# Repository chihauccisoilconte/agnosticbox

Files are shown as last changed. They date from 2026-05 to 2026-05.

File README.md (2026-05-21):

# Agnostic Box

This repository contains the files necessary to make an Agnostic Box.

The Agnostic Box is a versatile DMI (Digital Musical Instrument) that can be programmed in many ways. It is powered by an Arduino Nano ESP32, so it can run different interactive music, sound, and sensor-based sketches; this repository provides example sketches using the Mozzi audio synthesis library. The box is equipped with three potentiometers, three buttons, three LEDs, an MPU6050/GY-521 motion sensor connected over I2C, and a PAM8302A amplifier, giving it a compact set of tactile, visual, motion, and audio features for building custom musical interactions.

## Author

Created by [chihauccisoilconte](https://chihauccisoilconte.eu/).

The Agnostic Box is an idea by Raul Masu and Nicolo Merendino (aka chi ha ucciso il conte?).

## Contents

- `agnostic box instruction manual.pdf` - build and assembly documentation.
- `agnostic box PCB/` - KiCad PCB files, Gerber files, drill files, PCB exports, and related PCB assets.
- `agonstic box 3D models/` - FreeCAD source files and STL/3MF files for 3D-printed parts.
- `agnostic box 2d vectors/` - 2D vector files and sticker artwork.
- `agnostic box arduino nano esp32 code/` - Arduino Nano ESP32 sketches.

## License

MIT License

Copyright (c) 2026 chihauccisoilconte

Permission is hereby granted, free of charge, to any person obtaining a copy
of this repository and associated documentation files (the "Work"), to deal
in the Work without restriction, including without limitation the rights
to use, copy, modify, merge, publish, distribute, sublicense, and/or sell
copies of the Work, and to permit persons to whom the Work is furnished to do
so, subject to the following conditions:

The above copyright notice and this permission notice shall be included in all
copies or substantial portions of the Work.

THE WORK IS PROVIDED "AS IS", WITHOUT WARRANTY OF ANY KIND, EXPRESS OR
IMPLIED, INCLUDING BUT NOT LIMITED TO THE WARRANTIES OF MERCHANTABILITY,
FITNESS FOR A PARTICULAR PURPOSE AND NONINFRINGEMENT. IN NO EVENT SHALL THE
AUTHORS OR COPYRIGHT HOLDERS BE LIABLE FOR ANY CLAIM, DAMAGES OR OTHER
LIABILITY, WHETHER IN AN ACTION OF CONTRACT, TORT OR OTHERWISE, ARISING FROM,
OUT OF OR IN CONNECTION WITH THE WORK OR THE USE OR OTHER DEALINGS IN THE
WORK.

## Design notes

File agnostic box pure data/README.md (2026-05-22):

# Agnostic Box Pure Data Patch

This folder contains a Pure Data patch for using the Agnostic Box as a serial controller for FM synthesis.

The patch `arduino_controlling_FM_synth.pd` receives the serial array sent by the Arduino Nano ESP32, separates the values in Pure Data, and uses them to control an FM sine synthesizer.

## Install Pure Data

Download and install Pure Data Vanilla:

- Pure Data project site: <https://puredata.info/>
- Pure Data source and install notes: <https://github.com/pure-data/pure-data>
- Miller Puckette's Pd download page: <http://msp.ucsd.edu/software.html>

After installing Pd, open it once and check that audio works:

1. Open `Media > Audio Settings...`.
2. Select your audio input/output device.
3. Turn on `DSP` in the main Pd window.
4. Open `Media > Test Audio and MIDI...` if you want to confirm sound output.

## Install the `comport` External

The patch uses the `[comport]` object to read serial data from the Agnostic Box. `[comport]` is not part of Pd Vanilla, so install it with Deken, Pd's external/package manager.

Useful links:

- Deken documentation: <https://deken.puredata.info/docs>
- Deken external search: <https://deken.puredata.info/search.html>
- Pd external installation is also described in the Pure Data README: <https://github.com/pure-data/pure-data>

Install from inside Pure Data:

1. Open Pd.
2. Go to `Help > Find Externals...`.
3. Search for `comport`.
4. Install the package that matches your operating system.
5. Restart Pure Data.
6. Create a new object called `[comport]`. If it creates without an error, the install worked.

## Upload the Arduino Serial Sketch

Upload the mapped serial sketch to the Arduino Nano ESP32:

```text
../agnostic box arduino nano esp32 code/sensor_mapped_serial_test/sensor_mapped_serial_test.ino
```

That sketch sends seven values over serial:

```text
pot0 pot1 pot2 button0 button1 button2 gyro
```

The mapped values are:

- `pot0`, `pot1`, `pot2`: `1-127`
- `button0`, `button1`, `button2`: `0` or `1`
- `gyro`: `0-127`, based on `0-90` degrees, clamped for out-of-range motion

The Arduino sketch uses:

```cpp
Serial.begin(115200);
```

So the Pd patch should use the same baud rate:

```text
[comport 0 115200]
```

If the existing patch has another baud rate, edit the `[comport]` object so it matches the Arduino sketch.

## Connect the Agnostic Box to Pure Data

1. Connect the Agnostic Box by USB.
2. Close the Arduino Serial Monitor. Only one program can usually use the serial port at a time.
3. Open `arduino_controlling_FM_synth.pd` in Pure Data.
4. Turn on `DSP`.
5. Click the `devices` message in the patch.
6. Check the Pd console for the serial device list.
7. Change the `open 0` message if needed. For example, use `open 1`, `open 2`, etc. depending on the listed device number.
8. Click the correct `open` message.

If serial data is arriving, the number boxes after `[unpack f f f f f f f]` should update when you turn knobs, press buttons, or tilt the box.

## How the Serial Parsing Works

The Arduino sends a line of space-separated numbers, ending with a newline:

```text
64 23 127 0 1 0 45
```

In the Pd patch:

- `[comport]` receives raw serial bytes.
- `[sel 13 10]` detects carriage return and newline characters.
- The list-building objects collect each line.
- `[fudiparse]` converts the incoming text into Pd numbers.
- `[unpack f f f f f f f]` separates the seven values.

The value order is:

```text
1. pot0
2. pot1
3. pot2
4. button0
5. button1
6. button2
7. gyro
```

## Using the Values for FM Synthesis

FM synthesis uses one oscillator to modulate the frequency of another oscillator.

In this patch:

- `[osc~]` objects generate sine waves.
- `[mtof]` converts controller values into musical frequencies.
- `[*~]` scales modulation depth.
- `[+~]` adds modulation to the carrier frequency.
- `[dac~]` sends the final audio to the speakers.

A useful control layout is:

- `pot0`: carrier pitch
- `pot1`: modulator pitch
- `pot2`: modulation depth or output level
- `gyro`: extra modulation depth, feedback, or vibrato-like movement
- `button0`, `button1`, `button2`: enable/disable modulation paths, hold notes, or switch presets

Start with low volume before turning on DSP. FM patches can get loud quickly when modulation depth or feedback is high.

## Troubleshooting

- If `[comport]` says it cannot create, install the `comport` external with `Help > Find Externals...` and restart Pd.
- If the device will not open, close Arduino IDE Serial Monitor and any other serial terminal.
- If values do not move, click `devices`, confirm the device number, then send the matching `open` message.
- If the values look wrong, make sure the Pd baud rate matches `Serial.begin(115200)` in the Arduino sketch.
- On Linux, your user may need permission to access serial devices such as `/dev/ttyACM0` or `/dev/ttyUSB0`.

## Credits

Created for the Agnostic Box project by chihauccisoilconte.

This Pure Data patch uses Pure Data Vanilla and the `comport` external for serial communication.

## License

MIT License

Copyright (c) 2026 chihauccisoilconte

Permission is hereby granted, free of charge, to any person obtaining a copy
of this repository and associated documentation files (the "Work"), to deal
in the Work without restriction, including without limitation the rights
to use, copy, modify, merge, publish, distribute, sublicense, and/or sell
copies of the Work, and to permit persons to whom the Work is furnished to do
so, subject to the following conditions:

The above copyright notice and this permission notice shall be included in all
copies or substantial portions of the Work.

THE WORK IS PROVIDED "AS IS", WITHOUT WARRANTY OF ANY KIND, EXPRESS OR
IMPLIED, INCLUDING BUT NOT LIMITED TO THE WARRANTIES OF MERCHANTABILITY,
FITNESS FOR A PARTICULAR PURPOSE AND NONINFRINGEMENT. IN NO EVENT SHALL THE
AUTHORS OR COPYRIGHT HOLDERS BE LIABLE FOR ANY CLAIM, DAMAGES OR OTHER
LIABILITY, WHETHER IN AN ACTION OF CONTRACT, TORT OR OTHERWISE, ARISING FROM,
OUT OF OR IN CONNECTION WITH THE WORK OR THE USE OR OTHER DEALINGS IN THE
WORK.

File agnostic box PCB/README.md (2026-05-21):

# Agnostic Box PCB

This folder contains the PCB files for the Agnostic Box.

The PCB was made with [KiCad](https://www.kicad.org/), an open source electronics design suite. The folder includes KiCad project files, schematic and PCB layout files, Gerber files, drill files, board backups, graphics, footprints, and PCB export files.

Use the KiCad project files to inspect or modify the schematic and PCB layout. Use the Gerber and drill files when ordering or manufacturing the PCB.

For travel and safety, the standard Agnostic Box build does not include a battery. The PCB still includes the possibility of adding one through the battery footprint/connection, so builders can adapt the power setup if their use case requires it.

## License

MIT License

Copyright (c) 2026 chihauccisoilconte

Permission is hereby granted, free of charge, to any person obtaining a copy
of this repository and associated documentation files (the "Work"), to deal
in the Work without restriction, including without limitation the rights
to use, copy, modify, merge, publish, distribute, sublicense, and/or sell
copies of the Work, and to permit persons to whom the Work is furnished to do
so, subject to the following conditions:

The above copyright notice and this permission notice shall be included in all
copies or substantial portions of the Work.

THE WORK IS PROVIDED "AS IS", WITHOUT WARRANTY OF ANY KIND, EXPRESS OR
IMPLIED, INCLUDING BUT NOT LIMITED TO THE WARRANTIES OF MERCHANTABILITY,
FITNESS FOR A PARTICULAR PURPOSE AND NONINFRINGEMENT. IN NO EVENT SHALL THE
AUTHORS OR COPYRIGHT HOLDERS BE LIABLE FOR ANY CLAIM, DAMAGES OR OTHER
LIABILITY, WHETHER IN AN ACTION OF CONTRACT, TORT OR OTHERWISE, ARISING FROM,
OUT OF OR IN CONNECTION WITH THE WORK OR THE USE OR OTHER DEALINGS IN THE
WORK.

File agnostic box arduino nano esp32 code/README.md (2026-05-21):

# Agnostic Box Arduino Nano ESP32 Code

This folder contains Arduino sketches for the Agnostic Box.

The code is made for the Arduino Nano ESP32 and is intended to be opened and uploaded with the [Arduino IDE](https://www.arduino.cc/en/software). Some sketches use the [Mozzi](https://github.com/sensorium/Mozzi) audio synthesis library.

## Arduino IDE Setup

1. Install the Arduino IDE from <https://www.arduino.cc/en/software>.
2. Open the Arduino IDE.
3. Open `Tools > Board > Boards Manager...`.
4. Search for `Nano ESP32`.
5. Install the Arduino Nano ESP32 board package.
6. Select the board from `Tools > Board`.
7. Select the correct USB port from `Tools > Port`.

For generic ESP32 board support, add this URL in `File > Preferences > Additional boards manager URLs`, then install the `esp32` platform from Boards Manager:

```text
https://espressif.github.io/arduino-esp32/package_esp32_index.json
```

## Mozzi Library Setup

1. Open `Sketch > Include Library > Manage Libraries...`.
2. Search for `Mozzi`.
3. Install the Mozzi library.
4. Open one of the sketches in this folder.
5. Compile and upload it to the Arduino Nano ESP32.

## License

MIT License

Copyright (c) 2026 chihauccisoilconte

Permission is hereby granted, free of charge, to any person obtaining a copy
of this repository and associated documentation files (the "Work"), to deal
in the Work without restriction, including without limitation the rights
to use, copy, modify, merge, publish, distribute, sublicense, and/or sell
copies of the Work, and to permit persons to whom the Work is furnished to do
so, subject to the following conditions:

The above copyright notice and this permission notice shall be included in all
copies or substantial portions of the Work.

THE WORK IS PROVIDED "AS IS", WITHOUT WARRANTY OF ANY KIND, EXPRESS OR
IMPLIED, INCLUDING BUT NOT LIMITED TO THE WARRANTIES OF MERCHANTABILITY,
FITNESS FOR A PARTICULAR PURPOSE AND NONINFRINGEMENT. IN NO EVENT SHALL THE
AUTHORS OR COPYRIGHT HOLDERS BE LIABLE FOR ANY CLAIM, DAMAGES OR OTHER
LIABILITY, WHETHER IN AN ACTION OF CONTRACT, TORT OR OTHERWISE, ARISING FROM,
OUT OF OR IN CONNECTION WITH THE WORK OR THE USE OR OTHER DEALINGS IN THE
WORK.

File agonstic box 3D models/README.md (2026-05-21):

# Agnostic Box 3D Models

This folder contains the 3D model files for the Agnostic Box.

The source models were made with [FreeCAD](https://www.freecad.org/). The folder includes FreeCAD source files, STL files, and a 3MF file for 3D printing the mechanical parts.

It is recommended to 3D print the parts with PLA. Open the FreeCAD files if you need to inspect or modify the models, and use the STL or 3MF files for slicing and printing.

## License

MIT License

Copyright (c) 2026 chihauccisoilconte

Permission is hereby granted, free of charge, to any person obtaining a copy
of this repository and associated documentation files (the "Work"), to deal
in the Work without restriction, including without limitation the rights
to use, copy, modify, merge, publish, distribute, sublicense, and/or sell
copies of the Work, and to permit persons to whom the Work is furnished to do
so, subject to the following conditions:

The above copyright notice and this permission notice shall be included in all
copies or substantial portions of the Work.

THE WORK IS PROVIDED "AS IS", WITHOUT WARRANTY OF ANY KIND, EXPRESS OR
IMPLIED, INCLUDING BUT NOT LIMITED TO THE WARRANTIES OF MERCHANTABILITY,
FITNESS FOR A PARTICULAR PURPOSE AND NONINFRINGEMENT. IN NO EVENT SHALL THE
AUTHORS OR COPYRIGHT HOLDERS BE LIABLE FOR ANY CLAIM, DAMAGES OR OTHER
LIABILITY, WHETHER IN AN ACTION OF CONTRACT, TORT OR OTHERWISE, ARISING FROM,
OUT OF OR IN CONNECTION WITH THE WORK OR THE USE OR OTHER DEALINGS IN THE
WORK.

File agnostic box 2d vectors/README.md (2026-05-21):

# Agnostic Box 2D Vectors

This folder contains 2D vector files and graphic assets for the Agnostic Box.

The 2D files were made with [Inkscape](https://inkscape.org/) and [FreeCAD](https://www.freecad.org/). The graphics can be laser engraved, or they can be printed as stickers.

Use the vector files as source artwork for editing, engraving, cutting, or sticker production.

## License

MIT License

Copyright (c) 2026 chihauccisoilconte

Permission is hereby granted, free of charge, to any person obtaining a copy
of this repository and associated documentation files (the "Work"), to deal
in the Work without restriction, including without limitation the rights
to use, copy, modify, merge, publish, distribute, sublicense, and/or sell
copies of the Work, and to permit persons to whom the Work is furnished to do
so, subject to the following conditions:

The above copyright notice and this permission notice shall be included in all
copies or substantial portions of the Work.

THE WORK IS PROVIDED "AS IS", WITHOUT WARRANTY OF ANY KIND, EXPRESS OR
IMPLIED, INCLUDING BUT NOT LIMITED TO THE WARRANTIES OF MERCHANTABILITY,
FITNESS FOR A PARTICULAR PURPOSE AND NONINFRINGEMENT. IN NO EVENT SHALL THE
AUTHORS OR COPYRIGHT HOLDERS BE LIABLE FOR ANY CLAIM, DAMAGES OR OTHER
LIABILITY, WHETHER IN AN ACTION OF CONTRACT, TORT OR OTHERWISE, ARISING FROM,
OUT OF OR IN CONNECTION WITH THE WORK OR THE USE OR OTHER DEALINGS IN THE
WORK.

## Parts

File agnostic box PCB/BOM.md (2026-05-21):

# Agnostic Box PCB Bill of Materials

Source files checked:

- `agnostic box PCB.kicad_sch`
- `agnostic box PCB.kicad_pcb`

This BOM is based on the KiCad schematic symbols and PCB footprints. The schematic uses generic values for several parts, so values that are only visible in PCB reference labels are noted below.

## Components

| Qty | References | Component | Value / specification | Footprint / package | Notes |
| ---: | --- | --- | --- | --- | --- |
| 1 | A1 | Arduino Nano compatible module | Arduino Nano or Arduino Nano ESP32 | `Module:Arduino_Nano` | PCB silkscreen says `Arduino Nano (or Nano esp32)`. |
| 1 | U1 | GY-521 accelerometer/gyro module | GY-521 / MPU5060 label in schematic | `gy521:GY-521` | Manufacturer field: `GODREAM FORDREAM CO., LIMITED`; MP field: `GY-521`. |
| 1 | J1 | PAM8302A audio amplifier connection | PAM8302A | `Connector_PinSocket_2.54mm:PinSocket_1x05_P2.54mm_Vertical` | The PCB footprint is a 1x05 2.54 mm socket/header for the amplifier module. |
| 1 | BT1 | Battery connector | 2-pin battery connector | `Connector_PinSocket_2.54mm:PinSocket_1x02_P2.54mm_Vertical` | PCB silkscreen label: `battery`. |
| 3 | D1, D2, D3 | LED | 5 mm through-hole LED | `LED_THT:LED_D5.0mm` | PCB labels: `LED1(D4)`, `LED2(D5)`, `LED3(D6)`. LED color is not specified in the KiCad files. |
| 3 | R1, R2, R3 | Resistor | 220 ohm | `Resistor_THT:R_Axial_DIN0207_L6.3mm_D2.5mm_P7.62mm_Horizontal` | The schematic value is generic `R`; `220` comes from PCB labels `R1-220`, `R2-220`, `R3-220`. |
| 3 | R4, R5, R6 | Resistor | 10k ohm | `Resistor_THT:R_Axial_DIN0207_L6.3mm_D2.5mm_P7.62mm_Horizontal` | The schematic value is generic `R`; `10k` comes from PCB labels `R4-10k`, `R5-10k`, `R6-10k`. |
| 3 | RV1, RV2, RV3 | Potentiometer | Resistance value not specified | `Potentiometer_THT:Potentiometer_Alps_RK163_Single_Horizontal` | PCB labels: `RV1(A1)`, `RV2(A2)`, `RV3(A3)`. |
| 3 | SW1, SW2, SW3 | Push button | 6 mm through-hole push button | `Button_Switch_THT:SW_PUSH_6mm` | PCB labels: `SW1(D10)`, `SW2(D11)`, `SW3(D12)`. |

## PCB-Only Mechanical Features

| Qty | Item | Footprint | BOM status |
| ---: | --- | --- | --- |
| 3 | M3 countersunk mounting holes | `MountingHole:MountingHole_3.2mm_M3_DIN965` | Excluded from KiCad BOM; no screws or hardware values are specified in the board file. |

## Notes

- No manufacturer part numbers are specified for the resistors, LEDs, switches, potentiometers, battery connector, Arduino module, or PAM8302A connector in the KiCad schematic.
- The resistor values `220 ohm` and `10k ohm` were taken from PCB reference labels, not from schematic value fields.
- Potentiometer resistance values are not specified in either the schematic values or PCB labels.

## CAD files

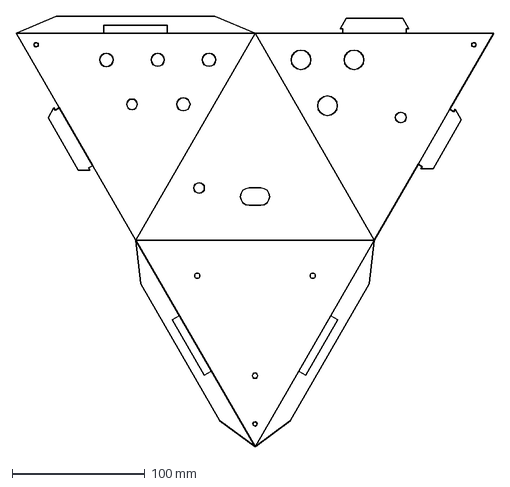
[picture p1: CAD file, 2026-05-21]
agnostic box 2d vectors/agnostic_box_pattern_workshop_final.dxf
360.0 x 324.8 mm

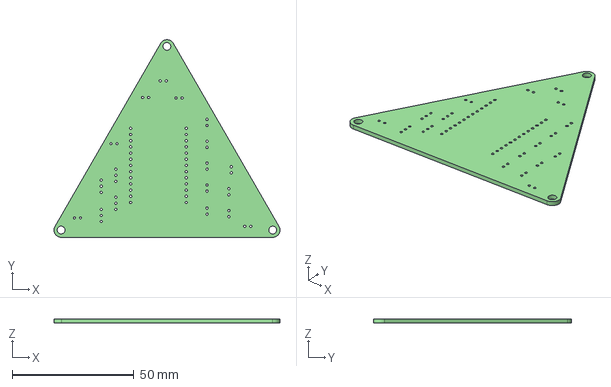
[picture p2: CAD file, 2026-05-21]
agnostic box PCB/agnostic box PCB.step
92.9 x 81.3 x 1.60 mm

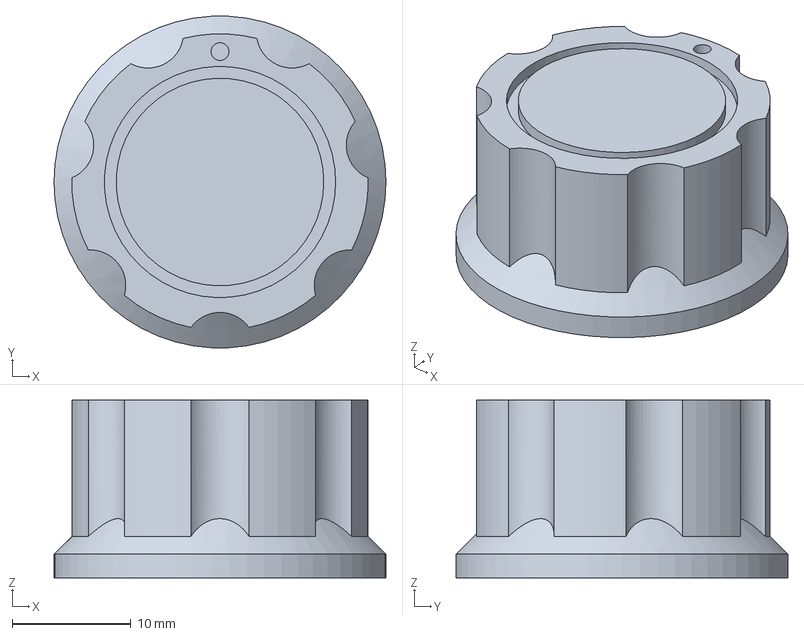
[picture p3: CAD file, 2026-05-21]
agonstic box 3D models/agnostic_box_nano_3d_models/knob.FCStd
28.0 x 28.0 x 15.0 mm

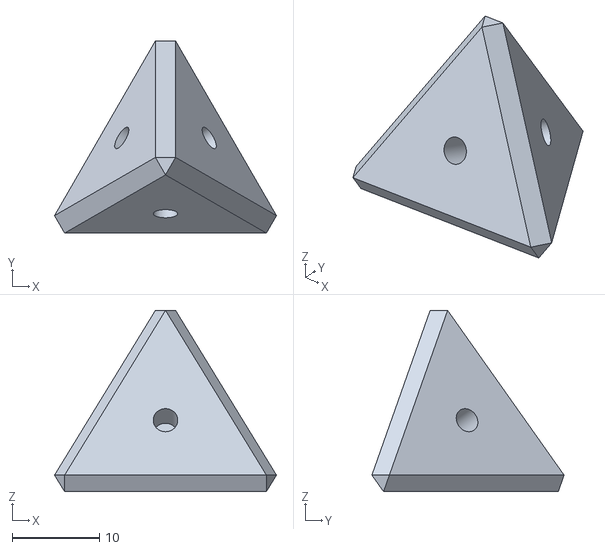
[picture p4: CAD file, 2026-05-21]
agonstic box 3D models/STL/4.2 - junction piece.stl
25.4 x 22.0 x 20.7

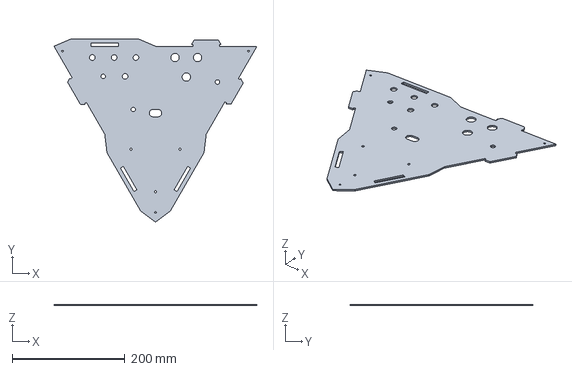
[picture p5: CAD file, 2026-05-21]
agnostic box 2d vectors/agnostic box pattern.FCStd
360.0 x 324.8 x 2.50 mm

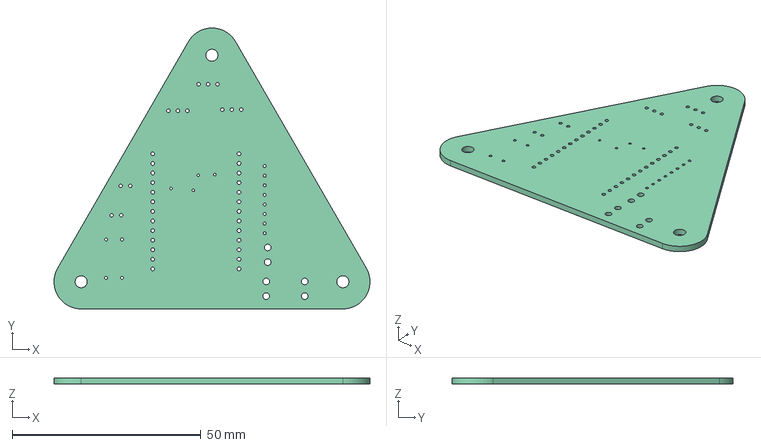
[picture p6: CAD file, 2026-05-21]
agnostic box PCB/pcb_3dmodel.FCStd
83.7 x 74.4 x 1.60 mm

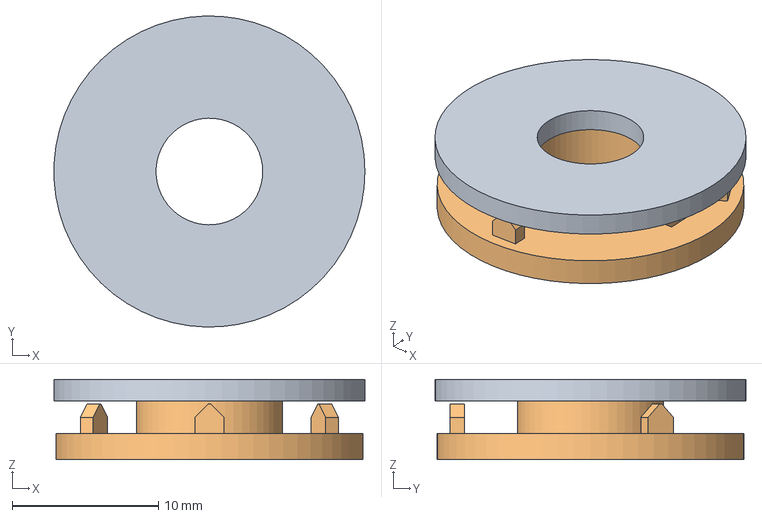
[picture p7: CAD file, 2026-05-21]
agonstic box 3D models/agnostic_box_nano_3d_models/knob_element.FCStd
21.3 x 21.3 x 5.50 mm
knob_piece_1
knob_piece_2

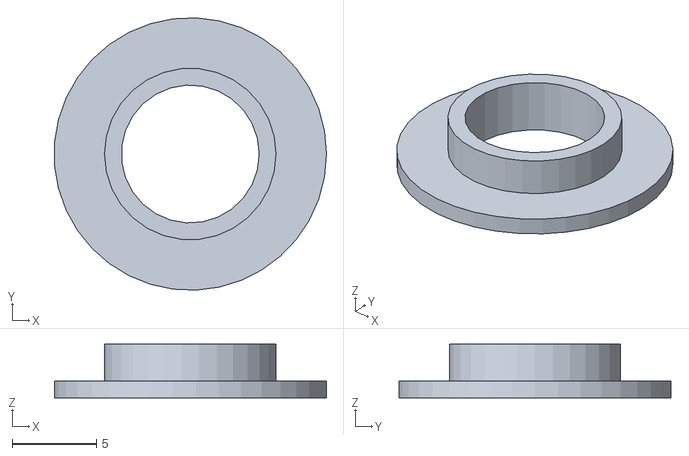
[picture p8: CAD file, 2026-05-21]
agonstic box 3D models/STL/3 - jack element 1 (thick).stl
16.2 x 16.2 x 3.20

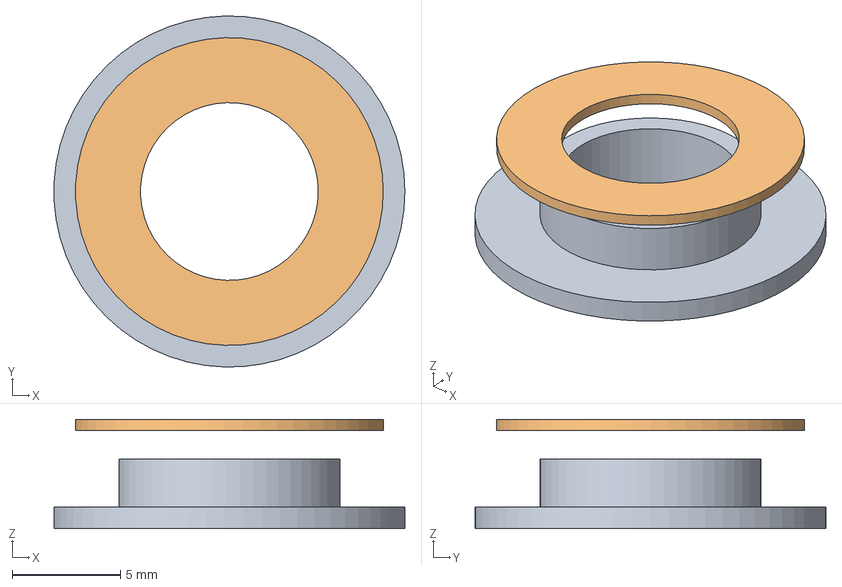
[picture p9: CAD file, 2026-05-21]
agonstic box 3D models/agnostic_box_nano_3d_models/jack__element-pop-os.FCStd
16.2 x 16.2 x 5.03 mm

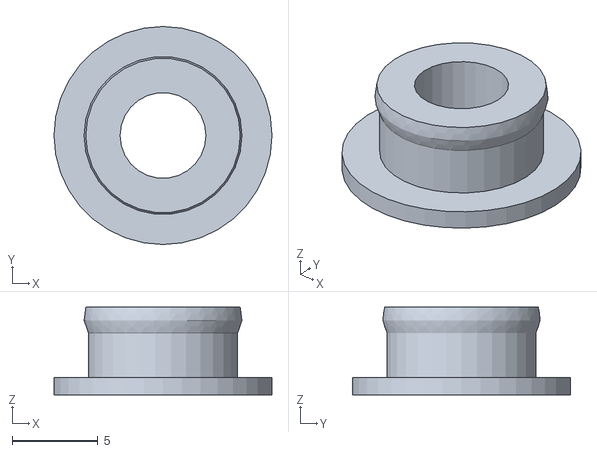
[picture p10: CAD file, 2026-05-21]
agonstic box 3D models/STL/7 - led holder.stl
12.7 x 12.7 x 5.10

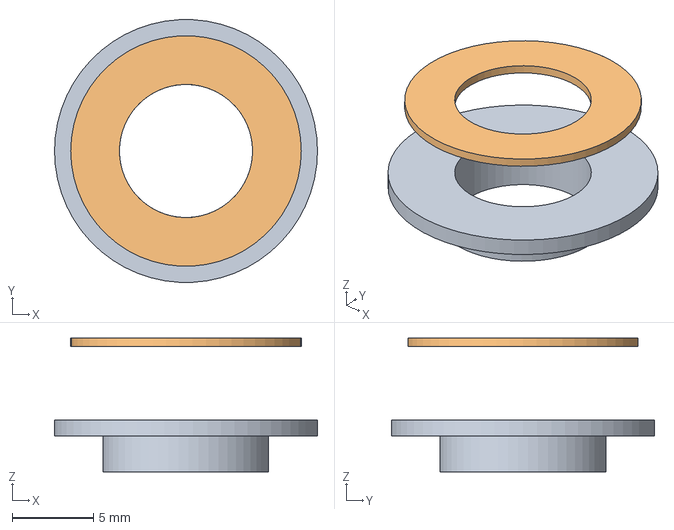
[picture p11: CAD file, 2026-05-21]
agonstic box 3D models/agnostic_box_nano_3d_models/jack__element.FCStd
16.2 x 16.2 x 8.23 mm

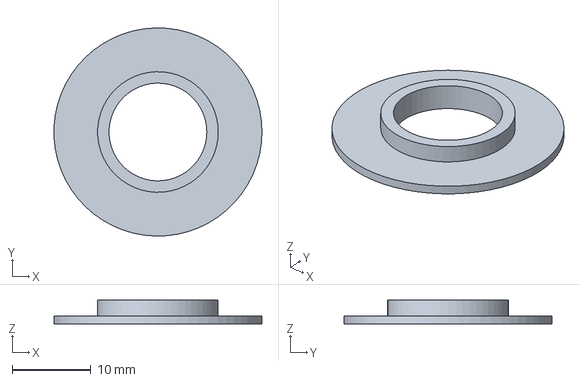
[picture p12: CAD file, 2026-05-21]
agonstic box 3D models/agnostic_box_nano_3d_models/button_element.FCStd
26.4 x 26.4 x 3.00 mm

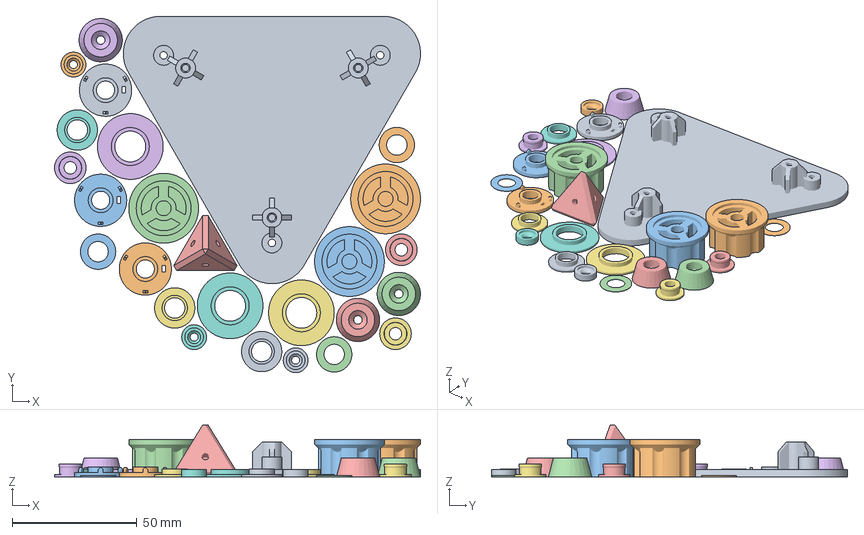
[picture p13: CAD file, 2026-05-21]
agonstic box 3D models/STL/agnostic_box_all.3mf
146.8 x 143.0 x 20.7 mm
1 - base.stl
5 - knob.stl x 3
4.2 - junction piece.stl
2 - button_element.stl x 3
6 - knob element.stl x 3
leg - element.stl x 3
3 - jack element 1 (thick).stl x 3
3.2 - jack element 2 (bearing).stl x 3
7 - led holder.stl x 3
4 junctioncap.stl x 3

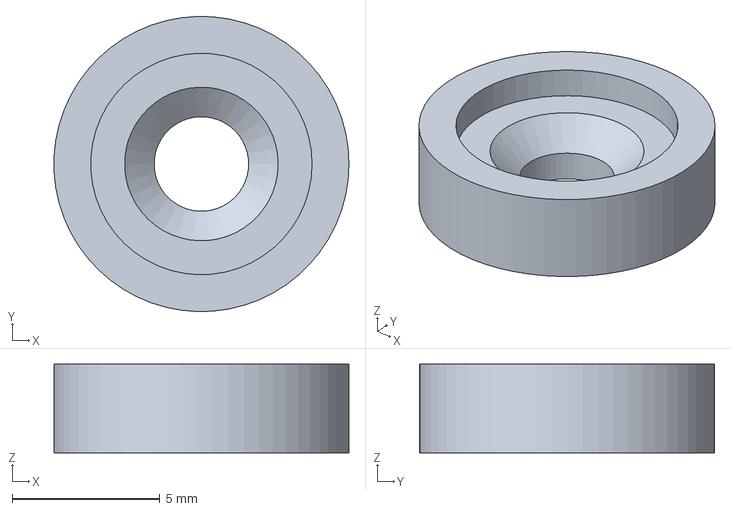
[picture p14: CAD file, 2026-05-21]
agonstic box 3D models/agnostic_box_nano_3d_models/junctioncap.FCStd
9.99 x 10.00 x 3.00 mm

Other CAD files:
agonstic box 3D models/STL/5 - knob.stl
agonstic box 3D models/STL/3.2 - jack element 2 (bearing).stl
agonstic box 3D models/agnostic_box_nano_3d_models/led_holder.FCStd
agonstic box 3D models/STL/6 - knob element.stl
agonstic box 3D models/STL/1 - base.stl
agonstic box 3D models/STL/2 - button_element.stl
agonstic box 3D models/STL/4 junctioncap.stl
agonstic box 3D models/STL/leg - element.stl
agonstic box 3D models/agnostic_box_nano_3d_models/base.FCStd
agonstic box 3D models/agnostic_box_nano_3d_models/junction element-pop-os.FCStd
agonstic box 3D models/agnostic_box_nano_3d_models/junction element.FCStd
agonstic box 3D models/agnostic_box_nano_3d_models/knob_element-pop-os.FCStd
agonstic box 3D models/agnostic_box_nano_3d_models/leg_element.FCStd

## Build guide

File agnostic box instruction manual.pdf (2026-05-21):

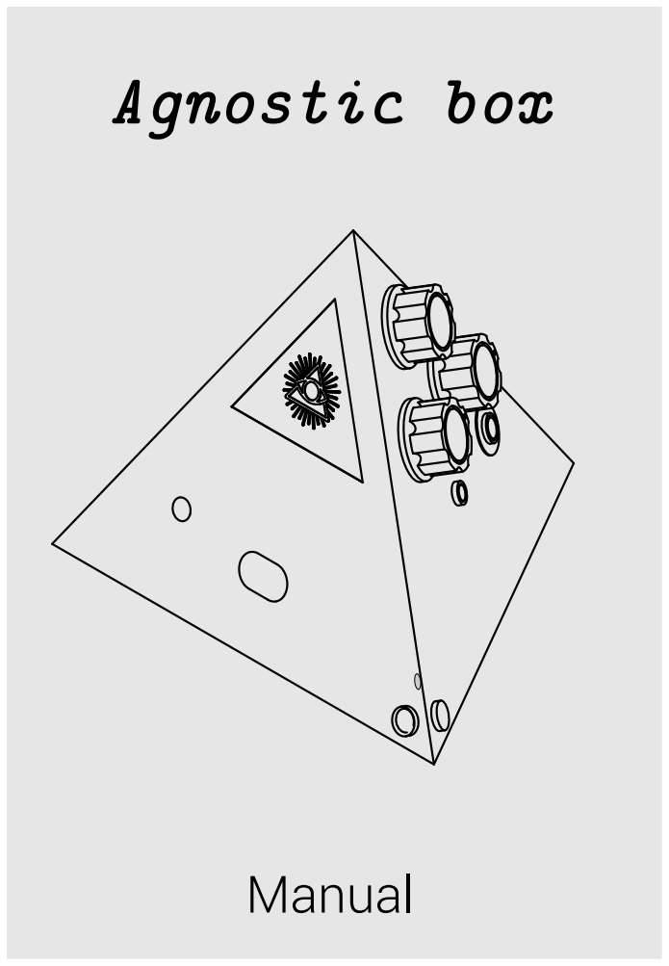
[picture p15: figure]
Agnostic box; Manual

MPU5060

PAM8302A

!

!

!

!

Resistors Colors
220 Ω
RD–RD–BK–BK–BN

### 10 kΩ

BN–BK–BK–RD–BN

The Agnostic Box is a completely open source, hackable sonic device designed for research and teaching. All source files and instructions are available in a public GitHub repository.

# Asnapshot!

Assemble the circuit using a soldering iron. Pay attention to the components that require a connector. The connector is there to allow easier assembly of a number of components.
The Arduino, amplifier, and acc/gyro should be placed on the PCB directly, though a connector is strongly recommended so you can eventually remove them and use them in other projects!
Note that the electronic components may differ from those shown in the images depending on the manufacturer, but the overall connections should be the same..

# Circuit

The folding lines of the
cardboard casing are
on the inside of the
box. It can be a good
idea to fold the pattern
first to get an idea of
how it works.

Note: For ease of
reading, messy wiring
is not visualized in
these illustrations.

# Cardboard pattern

# PCB placing

PCB support, casing
junction (be gentle on
that!), and LED
placement
Use hot glue to secure
the LED to the plastic
element.

Potentiometers, LED
(same as the others), and
audio jack
Make sure the orientation of the knobs is correct
(Wires perpendicular to the lower side of the face).

Switches and last LED
Disconnect the switches
using the connector, then
re-attach them.

Fold the cardboard
pattern
Keep the side with the
switch buttons as the
last part to fold. Then
secure the edges using
screws and bearings.

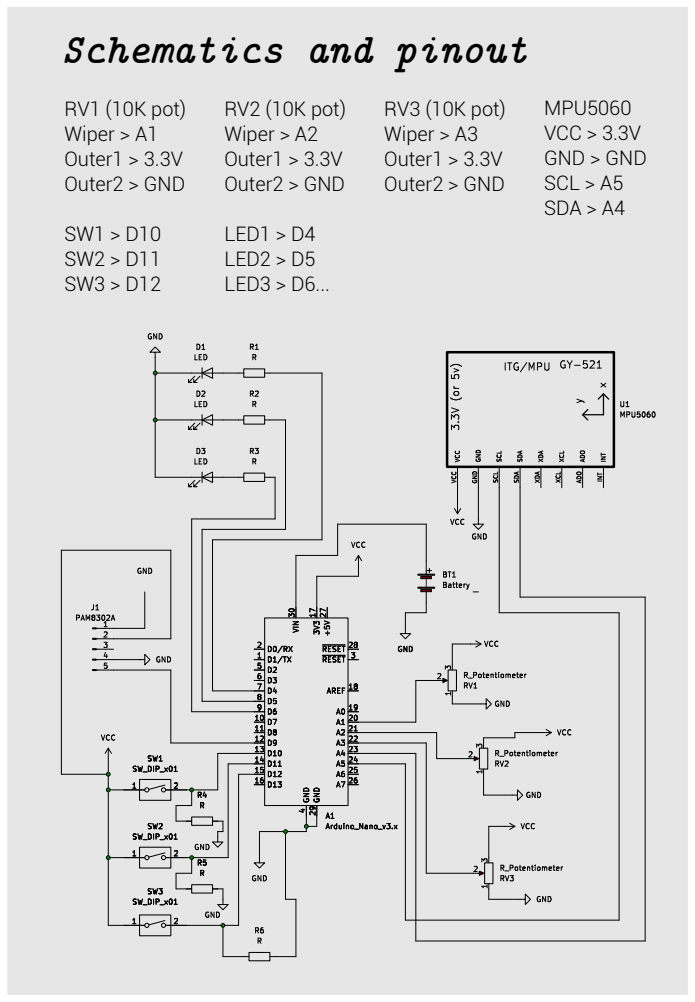
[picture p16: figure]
Schematics and pinout; MPU5060 VCC > 3.3V GND > GND SCL > A5 SDA > A4; RV3 (10K pot) Wiper > A3 Outer1 > 3.3V Outer2 > GND; LED1 > D4 LED2 > D5 LED3 > D6...; RV2 (10K pot) Wiper > A2 Outer1 > 3.3V Outer2 > GND; RV1 (10K pot) Wiper > A1 Outer1 > 3.3V Outer2 > GND

# Program the Agnostic Box!

What You'll Need
Hardware: Agnostic Box (Arduino Nano ESP32 inside) + USB-C cable
Software: Arduino IDE 2.x (arduino.cc/en/software)

Step-by-Step
Launch the IDE & Open Board Manager
Open the Arduino IDE. In the left sidebar, click the Boards Manager icon (cube shape).

Install the Board Package
In the search bar, type Nano ESP32. Click Install on the official Arduino ESP32 Boards package.

Connect Your Board
Plug the board into your computer using a USB-C cable.

Select Your Board
Click the board selector dropdown (often "Select Other Board & Port"). Find and select Arduino Nano ESP32. If two versions appear, choose the one labeled USB.

Write & Upload Your Code
Blink test: Go to File -> Examples -> 01.Basics -> Blink. Compile: Click the checkmark (top-left).

Upload: Click the right arrow next to it.

See the result
The built-in RGB LED on the board should start blinking.

Note - if your Agnostic Box is equipped with a classic Arduino Nano (or clone) you don't need any of this (but beware: no bluetooth and no wifi available)

# Meet the Agnostic Box!

The Agnostic Box is a simple and hackable sonic device designed for research and teaching purposes.
It contains 3 knobs, 3 buttons, a mono audio out jack, and an MPU6050 that detects acceleration and orientation.
The device is driven by an ESP32 Arduino Nano board, but it can also be used with a traditional Arduino Nano.
It is extremely versatile and can be programmed in many different ways according to your needs.
This device is completely open source. You can find all the source files and instructions in a public repository on GitHub.

By default the agnostic box is programmed with a Dub Siren-ish digital sythn that you can just plug to a speaker, but you can du much more...

# Agnostic Box and the Mozzi Library

# Agnostic Box and the BLE MIDI Library

The Mozzi library transforms your Agnostic Box into a powerful, standalone digital synthesizer. It's a sound synthesis library for Arduino that allows you to generate complex audio like growls, sweeps, and chorusing atmospherics using synthesis units like oscillators, delays, filters, and envelopes. For your box, the three knobs could control synthesis parameters such as frequency, filter cutoff, or amplitude. The three buttons could trigger different sound banks or envelopes. The MPU5060 could introduce gesture-controlled pitch bends or vibrato, while the three LEDs can provide real-time visual feedback of the synthesis state. Mozzi is available for the ESP32, making it a perfect fit for the Nano ESP32. The easiest way to get started is to install it directly from the Arduino Library Manager

# Agnostic Box and OSC Protocol

# Agnostic Box and whatever

https://github.com/sensorium/Mozzihttps://sensorium.github.io/Mozzi/https://docs.arduino.cc/hardware/nano-esp32

By using the BLE-MIDI protocol, your Agnostic Box becomes a natively recognized MIDI peripheral. This means that once connected, your computer, smartphone, or tablet will see the box as any other commercial Bluetooth MIDI controller—no special drivers or bridge scripts are required. This is because the Arduino Nano ESP32's ESP32-S3 chip, part of the u-blox NORA-W106 module, supports both Wi-Fi and Bluetooth Low Energy (LE). The key detail is that the Nano ESP32 is an ESP32-S3, which, unlike older ESP32 chips, can support MIDI over both BLE and USB simultaneously. In this setup, the three LEDs on your box can even be controlled by incoming MIDI messages from the DAW, creating a fully bidirectional wireless instrument.

https://www.midi.org/specifications/midi-transports-specifications/midi-over-bluetooth-lehttps://docs.arduino.cc/hardware/nano-esp32https://github.com/lathoub/arduin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

Open Sound Control (OSC) offers a more flexible and higher-resolution alternative to MIDI, and with the Nano ESP32's built-in Wi-Fi, you can implement this natively. You can use the MicroOsc library, a simple and lightweight Open Sound Control (OSC) library that supports the ESP32 platform. Your Agnostic Box can act as an OSC client over Wi-Fi, streaming sensor data directly. For instance, the three knobs could send float values as OSC messages like /box/ knob1 0.67, and the MPU5060 could send /box/imu/roll 45.2 to a target IP address and port where software like Pure Data or Max/ MSP is listening. MicroOsc provides a unified API to work over UDP (Ethernet or WiFi), making it ideal for this application. This approach avoids the need for a computer as a bridge, maintaining a clean and direct wireless connection.

https://explore.market.dev/ecosystems/arduino/projects/microoschttps://github.com/CNMAT/OSChttps://docs.arduino.cc/hardware/nano-esp32

Beyond synthesis and MIDI/OSC control, the Agnostic Box can serve as a multi‑purpose musical tool. The combination of knobs, buttons, an IMU, and LEDs makes it ideal for gestural performance: tilt the box to control filter sweeps while pressing buttons to trigger samples. You could use the MPU5060’s gyroscope to map bowing or shaking gestures to pitch bends, vibrato depth, or delay feedback. The three LEDs can be programmed as a visual metronome (blinking at BPM‑synced rates) or as a feedback display for note velocities. Over Wi‑Fi (using the Nano ESP32’s built‑in radio), the box can stream real‑time sensor data to a networked sound server running SuperCollider or Pure Data. Alternatively, use the board’s USB port to emulate a class‑compliant MIDI device—plugging directly into a computer without any driver installation. With the onboard memory, you could even store short wavetables or drum samples, turning the box into a minimal groovebox when combined with Mozzi’s sample playback features. The same three buttons could be repurposed as a step sequencer interface: each button toggles a step on/off, while knobs adjust pitch or velocity per step, and the LEDs light up to show the current playhead position. In an educational context, the box becomes a tangible platform for teaching synthesis, mapping, and sensor‑to‑sound relationships—all without soldering or external hardware beyond the Arduino Nano ESP32 itself.

# Credits

The agnostic box concept comes from an original idea from Raul Masu and Nicolo Merendino (aka "Chi ha Ucciso Il Conte?")

Design of the box and of this manual is by Nicolo Merendino (aka "Chi ha Ucciso Il Conte?")

Project funded by the HKUST-GZ

More info - chihauccisoilconte.eu

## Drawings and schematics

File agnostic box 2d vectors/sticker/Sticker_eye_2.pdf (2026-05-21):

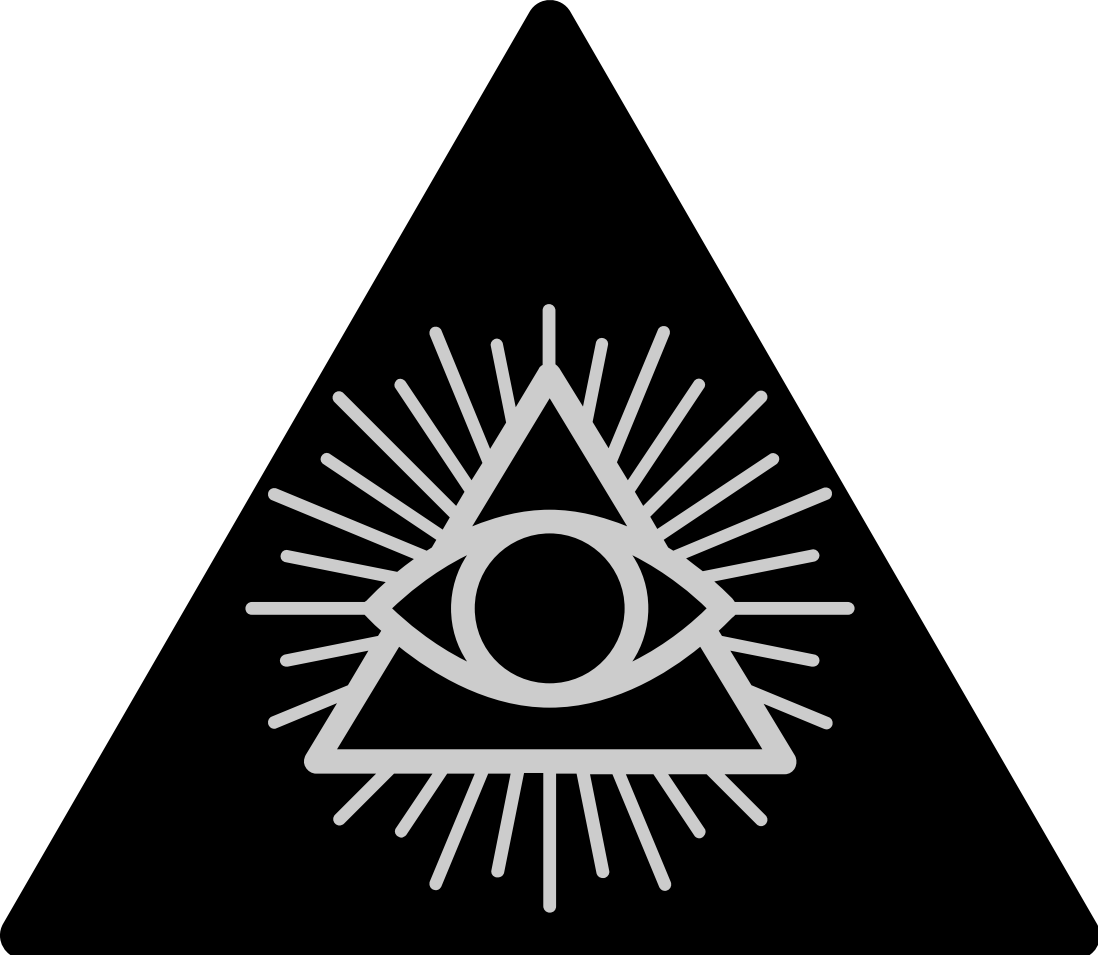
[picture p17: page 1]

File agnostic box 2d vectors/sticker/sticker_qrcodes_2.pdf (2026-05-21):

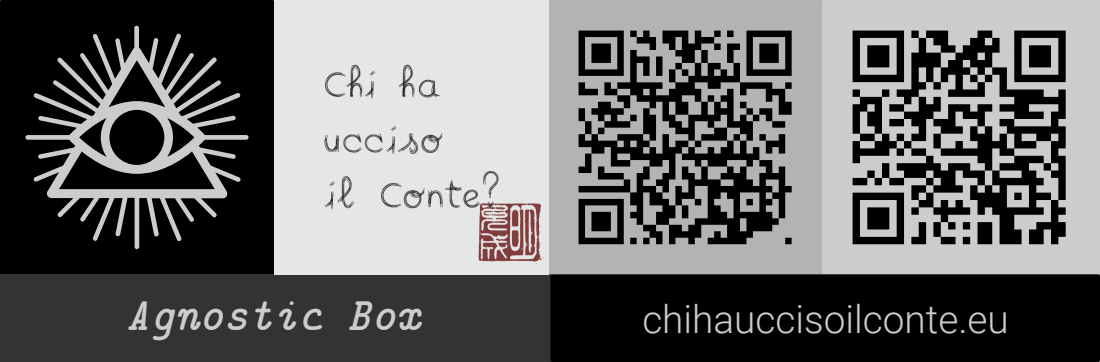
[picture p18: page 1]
Agnostic Box; chihauccisoilconte.eu

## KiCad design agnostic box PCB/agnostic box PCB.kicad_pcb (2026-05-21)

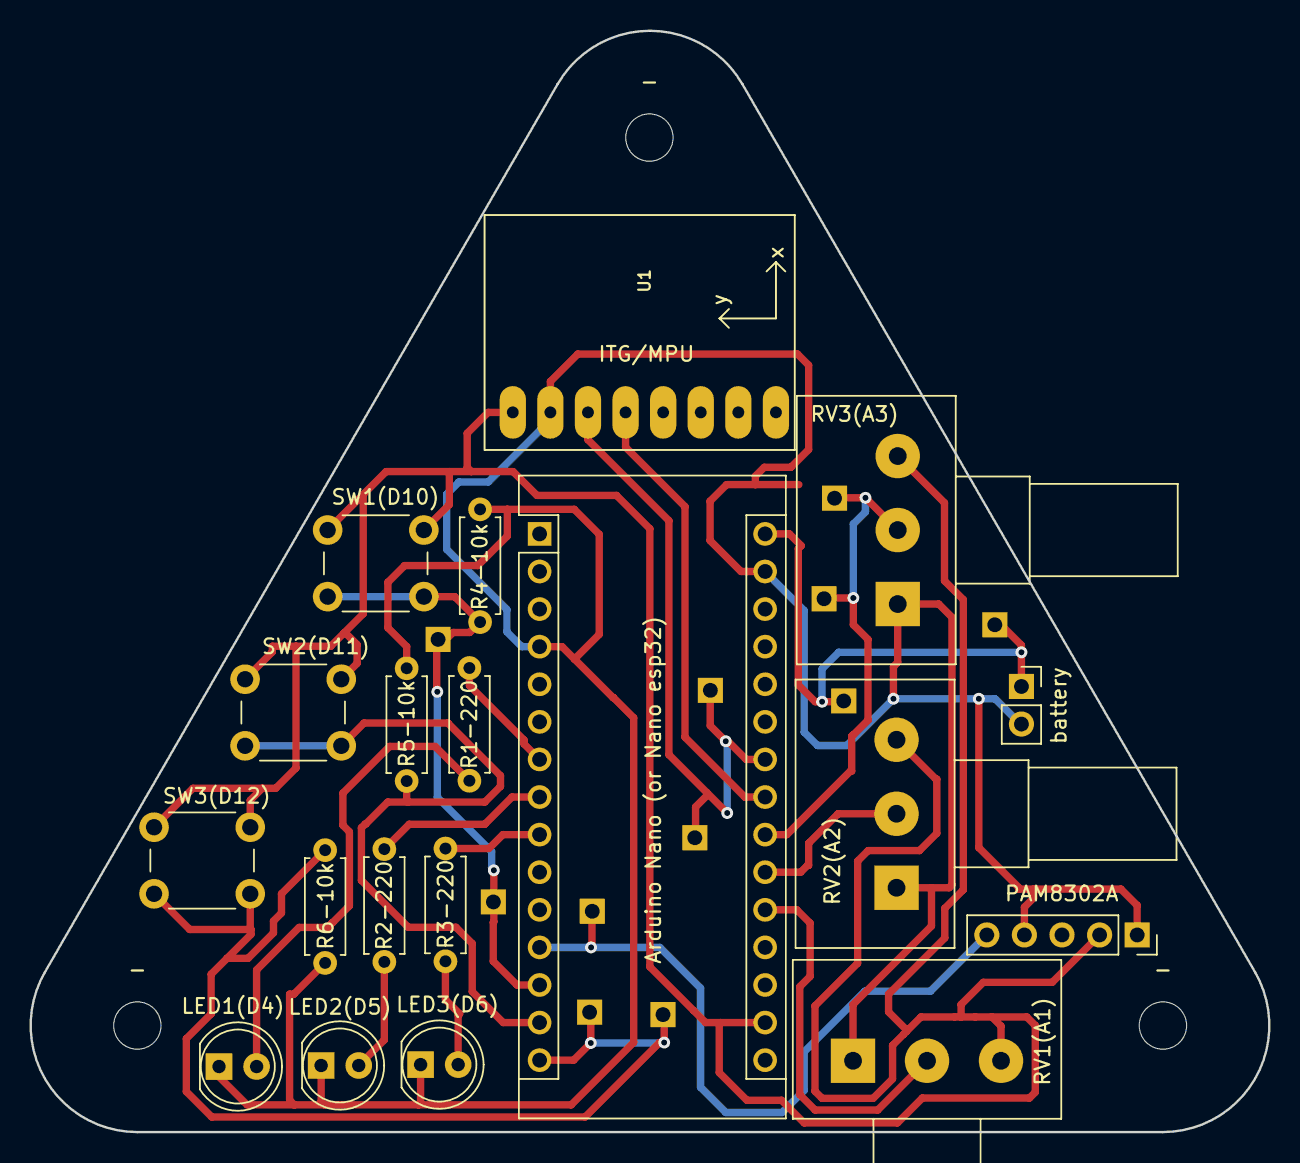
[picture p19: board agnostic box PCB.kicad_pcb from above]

Board: 2 copper layers, 83.7 x 74.4 mm, 22 parts (0 on the bottom side), 12 nets.

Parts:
-: MountingHole_3.2mm_M3_DIN965
-#2, -#3: MountingHole_3.2mm_M3_DIN965
Arduino Nano (or Nano esp32): Arduino_Nano_v3.x; Arduino_Nano
LED1(D4), LED2(D5), LED3(D6): LED; LED_D5.0mm
PAM8302A: PAM8302A; PinSocket_1x05_P2.54mm_Vertical
R1-220, R2-220, R3-220, R4-10k, R5-10k, R6-10k: R; R_Axial_DIN0207_L6.3mm_D2.5mm_P7.62mm_Horizontal
RV1(A1), RV2(A2), RV3(A3): R_Potentiometer; Potentiometer_Alps_RK163_Single_Horizontal
SW1(D10), SW2(D11), SW3(D12): SW_DIP_x01; SW_PUSH_6mm
U1: GY-521
battery: Battery; PinSocket_1x02_P2.54mm_Vertical

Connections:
GND: Arduino Nano (or Nano esp32).4 (GND), Arduino Nano (or Nano esp32).29 (GND), LED1(D4).1 (K), LED2(D5).1 (K), LED3(D6).1 (K), PAM8302A.1, PAM8302A.4, R4-10k.2, R5-10k.2, R6-10k.1, RV1(A1).1, RV2(A2).1, RV3(A3).1, U1.GND, battery.2 (-)
unnamed: Arduino Nano (or Nano esp32).20 (A1), RV1(A1).2
unnamed: Arduino Nano (or Nano esp32).21 (A2), RV2(A2).2
unnamed: Arduino Nano (or Nano esp32).22 (A3), RV3(A3).2
unnamed: Arduino Nano (or Nano esp32).23 (A4), U1.SDA
unnamed: Arduino Nano (or Nano esp32).24 (A5), U1.SCL
unnamed: Arduino Nano (or Nano esp32).12 (D9), PAM8302A.5
unnamed: Arduino Nano (or Nano esp32).13 (D10), SW1(D10).2
unnamed: Arduino Nano (or Nano esp32).14 (D11), SW2(D11).2
unnamed: Arduino Nano (or Nano esp32).15 (D12), SW3(D12).2
unnamed: Arduino Nano (or Nano esp32).30 (VIN), battery.1 (+)
VCC: Arduino Nano (or Nano esp32).17 (3V3), PAM8302A.2, RV1(A1).3, RV2(A2).3, RV3(A3).3, SW1(D10).1, SW2(D11).1, SW3(D12).1, U1.VCC

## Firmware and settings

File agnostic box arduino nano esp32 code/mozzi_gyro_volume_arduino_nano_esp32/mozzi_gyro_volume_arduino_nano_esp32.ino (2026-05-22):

#define MOZZI_AUDIO_MODE MOZZI_OUTPUT_PWM
#define MOZZI_AUDIO_PIN_1 D9

#include <Wire.h>
#include <Mozzi.h>
#include <Oscil.h>
#include <tables/sin2048_int8.h>
#include <tables/saw2048_int8.h>
#include <tables/square_no_alias_2048_int8.h>

#define CONTROL_RATE 128

const int MPU = 0x68;

const int POT_PITCH  = A1;
const int POT_VOLUME = A2;
const int POT_ECHO   = A3;

const int BTN_SINE   = D10;
const int BTN_SAW    = D11;
const int BTN_SQUARE = D12;

const int LED_SINE   = D4;
const int LED_SAW    = D5;
const int LED_SQUARE = D6;

Oscil<SIN2048_NUM_CELLS, AUDIO_RATE> sineOsc(SIN2048_DATA);
Oscil<SAW2048_NUM_CELLS, AUDIO_RATE> sawOsc(SAW2048_DATA);
Oscil<SQUARE_NO_ALIAS_2048_NUM_CELLS, AUDIO_RATE> squareOsc(SQUARE_NO_ALIAS_2048_DATA);
Oscil<SIN2048_NUM_CELLS, CONTROL_RATE> lfo(SIN2048_DATA);

bool sineHeld = false;
bool sawHeld = false;
bool squareHeld = false;

float accX = 0;
float accZ = 0;
float gyroY = 0;
float gyroOffsetY = 0;
float angleYZero = 0;
float compAngleY = 0;
unsigned long previousMpuTime = 0;

#define ECHO_SIZE 2048
int8_t echoBuffer[ECHO_SIZE];
int echoIndex = 0;
int echoMix = 0;
int echoFeedback = 0;
int volumeLevel = 127;

unsigned long lastPrint = 0;

float mapFloat(float value, float inMin, float inMax, float outMin, float outMax) {
  return (value - inMin) * (outMax - outMin) / (inMax - inMin) + outMin;
}

void setup() {
  Serial.begin(115200);
  delay(1000);

  analogReadResolution(12);

  Wire.begin();

  Wire.beginTransmission(MPU);
  Wire.write(0x6B);
  Wire.write(0x00);
  Wire.endTransmission(true);

  delay(100);
  calibrateMpu();
  previousMpuTime = millis();

  pinMode(BTN_SINE, INPUT_PULLUP);
  pinMode(BTN_SAW, INPUT_PULLUP);
  pinMode(BTN_SQUARE, INPUT_PULLUP);

  pinMode(LED_SINE, OUTPUT);
  pinMode(LED_SAW, OUTPUT);
  pinMode(LED_SQUARE, OUTPUT);

  lfo.setFreq(5.0f);

  Serial.println("3 oscillator Mozzi synth with MPU6050 vibrato and volume knob");

  startMozzi(CONTROL_RATE);
}

void updateControl() {
  updateMpuAngle();

  int pPitch = analogRead(POT_PITCH);
  int pVolume = analogRead(POT_VOLUME);
  int pEcho = analogRead(POT_ECHO);

  sineHeld   = digitalRead(BTN_SINE) == HIGH;
  sawHeld    = digitalRead(BTN_SAW) == HIGH;
  squareHeld = digitalRead(BTN_SQUARE) == HIGH;

  digitalWrite(LED_SINE, sineHeld);
  digitalWrite(LED_SAW, sawHeld);
  digitalWrite(LED_SQUARE, squareHeld);

  float baseFreq = map(pPitch, 0, 4095, 80, 900);

  float tiltAmount = constrain(abs(compAngleY), 0.0f, 45.0f);
  float modDepth = mapFloat(tiltAmount, 0.0f, 45.0f, 0.0f, 80.0f);
  float lfoRate = mapFloat(tiltAmount, 0.0f, 45.0f, 2.0f, 9.0f);

  lfo.setFreq(lfoRate);

  int lfoValue = lfo.next();
  float vibrato = ((float)lfoValue / 127.0f) * modDepth;

  float freq = baseFreq + vibrato;
  if (freq < 40.0f) freq = 40.0f;

  sineOsc.setFreq(freq);
  sawOsc.setFreq(freq * 0.995f);
  squareOsc.setFreq(freq * 1.005f);

  volumeLevel = map(pVolume, 0, 4095, 0, 127);
  echoMix = map(pEcho, 0, 4095, 0, 90);
  echoFeedback = map(pEcho, 0, 4095, 0, 95);

  if (millis() - lastPrint > 250) {
    lastPrint = millis();

    Serial.print("Pitch:");
    Serial.print(pPitch);

    Serial.print(" Volume:");
    Serial.print(pVolume);

    Serial.print(" Echo:");
    Serial.print(pEcho);

    Serial.print(" | GyroY angle:");
    Serial.print(compAngleY, 1);

    Serial.print(" | ModDepth:");
    Serial.print(modDepth, 1);

    Serial.print(" | LfoRate:");
    Serial.print(lfoRate, 1);

    Serial.print(" | Freq:");
    Serial.print(freq);

    Serial.print(" | Sine:");
    Serial.print(sineHeld);

    Serial.print(" Saw:");
    Serial.print(sawHeld);

    Serial.print(" Square:");
    Serial.println(squareHeld);
  }
}

AudioOutput updateAudio() {
  int mix = 0;

  if (sineHeld) {
    mix += sineOsc.next();
  } else {
    sineOsc.next();
  }

  if (sawHeld) {
    mix += sawOsc.next();
  } else {
    sawOsc.next();
  }

  if (squareHeld) {
    mix += squareOsc.next();
  } else {
    squareOsc.next();
  }

  if (!sineHeld && !sawHeld && !squareHeld) {
    mix = 0;
  }

  int heldCount = 0;
  if (sineHeld) heldCount++;
  if (sawHeld) heldCount++;
  if (squareHeld) heldCount++;

  if (heldCount >= 2) {
    mix = mix / heldCount;
  }

  mix = (mix * volumeLevel) >> 7;

  int delayed = echoBuffer[echoIndex];

  int withEcho = mix + ((delayed * echoMix) >> 7);
  int feedbackSample = mix + ((delayed * echoFeedback) >> 7);

  if (feedbackSample > 127) feedbackSample = 127;
  if (feedbackSample < -128) feedbackSample = -128;

  echoBuffer[echoIndex] = feedbackSample;

  echoIndex++;
  if (echoIndex >= ECHO_SIZE) echoIndex = 0;

  if (withEcho > 127) withEcho = 127;
  if (withEcho < -128) withEcho = -128;

  return MonoOutput::from8Bit(withEcho);
}

void loop() {
  audioHook();
}

void updateMpuAngle() {
  readMpu();

  unsigned long currentTime = millis();
  float elapsedTime = (currentTime - previousMpuTime) / 1000.0f;
  previousMpuTime = currentTime;

  float angleY = atan2(-accX, accZ) * 180.0f / PI;
  float frontY = angleY - angleYZero;

  compAngleY = 0.96f * (compAngleY + gyroY * elapsedTime) + 0.04f * frontY;
}

void readMpu() {
  Wire.beginTransmission(MPU);
  Wire.write(0x3B);
  Wire.endTransmission(false);
  Wire.requestFrom(MPU, 14, true);

  int16_t rawAccX = Wire.read() << 8 | Wire.read();
  Wire.read();
  Wire.read();
  int16_t rawAccZ = Wire.read() << 8 | Wire.read();

  Wire.read();
  Wire.read();

  Wire.read();
  Wire.read();
  int16_t rawGyroY = Wire.read() << 8 | Wire.read();
  Wire.read();
  Wire.read();

  accX = rawAccX / 16384.0f;
  accZ = rawAccZ / 16384.0f;
  gyroY = rawGyroY / 131.0f - gyroOffsetY;
}

void calibrateMpu() {
  Serial.println("Calibrating MPU6050... keep it still.");

  const int samples = 300;
  float gyroSumY = 0;
  float angleSumY = 0;

  for (int i = 0; i < samples; i++) {
    readMpu();

    gyroSumY += gyroY;
    angleSumY += atan2(-accX, accZ) * 180.0f / PI;

    delay(5);
  }

  gyroOffsetY = gyroSumY / samples;
  angleYZero = angleSumY / samples;
  compAngleY = 0;

  Serial.println("IMU Calibration Complete");
}

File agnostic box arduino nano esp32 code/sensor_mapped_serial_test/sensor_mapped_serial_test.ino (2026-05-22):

/*
  Arduino Nano ESP32
  MPU6050 + 3 Pots + 3 Buttons + 3 LEDs

  Serial array:
  [pot0Mapped, pot1Mapped, pot2Mapped, button0, button1, button2, gyroMapped]

  Pot values are mapped from 12-bit ADC range 0-4095 to 1-127.
  Gyro angle value maps 0-90 degrees to 0-127.
  Gyro values below 0 clamp to 0.
  Gyro values above 127 clamp to 120.

  Connections:
  A1 -> pot 0
  A2 -> pot 1
  A3 -> pot 2

  D10 -> button 0
  D11 -> button 1
  D12 -> button 2

  D6 -> LED 0
  D5 -> LED 1
  D4 -> LED 2

  A4 -> SDA
  A5 -> SCL
*/

#include <Wire.h>

const int MPU = 0x68;

// MPU values
float AccX, AccZ;
float GyroY;
float angleYZero;
float compAngleY = 0;
float GyroErrorY;
float elapsedTime, currentTime, previousTime;

// LEDs
const int ledPin0 = D6;
const int ledPin1 = D5;
const int ledPin2 = D4;

// Pots
const int potPin0 = A1;
const int potPin1 = A2;
const int potPin2 = A3;

// Buttons
const int buttonPin0 = D10;
const int buttonPin1 = D11;
const int buttonPin2 = D12;
const int buttonPressedState = HIGH;

// Data array
int sensorData[7];

// Smoothing
const float alpha = 0.05;
float pot0Smooth = 0;
float pot1Smooth = 0;
float pot2Smooth = 0;

void setup() {
  Serial.begin(115200);
  delay(1000);

  analogReadResolution(12); // Nano ESP32: 0-4095

  Wire.begin();
  // If needed, use this instead:
  // Wire.begin(A4, A5);

  // Wake MPU6050
  Wire.beginTransmission(MPU);
  Wire.write(0x6B);
  Wire.write(0x00);
  Wire.endTransmission(true);

  delay(100);

  calculate_IMU_error();

  pinMode(ledPin0, OUTPUT);
  pinMode(ledPin1, OUTPUT);
  pinMode(ledPin2, OUTPUT);

  pinMode(buttonPin0, INPUT);
  pinMode(buttonPin1, INPUT);
  pinMode(buttonPin2, INPUT);

  Serial.println("Nano ESP32 mapped serial sensor test ready");
}

void loop() {
  accgyro();

  int raw0 = analogRead(potPin0);
  int raw1 = analogRead(potPin1);
  int raw2 = analogRead(potPin2);

  pot0Smooth = alpha * raw0 + (1.0 - alpha) * pot0Smooth;
  pot1Smooth = alpha * raw1 + (1.0 - alpha) * pot1Smooth;
  pot2Smooth = alpha * raw2 + (1.0 - alpha) * pot2Smooth;

  // Active-high buttons: pressed = 1, released = 0
  int btn0 = digitalRead(buttonPin0) == buttonPressedState ? 1 : 0;
  int btn1 = digitalRead(buttonPin1) == buttonPressedState ? 1 : 0;
  int btn2 = digitalRead(buttonPin2) == buttonPressedState ? 1 : 0;

  sensorData[0] = mapPotToMidi((int)pot0Smooth);
  sensorData[1] = mapPotToMidi((int)pot1Smooth);
  sensorData[2] = mapPotToMidi((int)pot2Smooth);
  sensorData[3] = btn0;
  sensorData[4] = btn1;
  sensorData[5] = btn2;
  sensorData[6] = mapGyroToMidi(compAngleY);

  int brightness0 = map(sensorData[0], 1, 127, 0, 255);
  int brightness1 = map(sensorData[1], 1, 127, 0, 255);
  int brightness2 = map(sensorData[2], 1, 127, 0, 255);

  analogWrite(ledPin0, btn0 ? brightness0 : 0);
  analogWrite(ledPin1, btn1 ? brightness1 : 0);
  analogWrite(ledPin2, btn2 ? brightness2 : 0);

  printArray(sensorData, 7);

  delay(10);
}

int mapPotToMidi(int value) {
  value = constrain(value, 0, 4095);
  return map(value, 0, 4095, 1, 127);
}

int mapGyroToMidi(float angle) {
  int mappedValue = map((int)angle, 0, 90, 0, 127);

  if (mappedValue < 0) {
    return 0;
  }

  if (mappedValue > 127) {
    return 120;
  }

  return mappedValue;
}

void printArray(int arr[], int length) {
  for (int i = 0; i < length; i++) {
    Serial.print(arr[i]);
    Serial.print(" ");
  }
  Serial.println();
}

void accgyro() {
  Wire.beginTransmission(MPU);
  Wire.write(0x3B);
  Wire.endTransmission(false);
  Wire.requestFrom(MPU, 14, true);

  int16_t rawAccX = Wire.read() << 8 | Wire.read();
  Wire.read();
  Wire.read();
  int16_t rawAccZ = Wire.read() << 8 | Wire.read();

  Wire.read();
  Wire.read();

  Wire.read();
  Wire.read();
  int16_t rawGyroY = Wire.read() << 8 | Wire.read();
  Wire.read();
  Wire.read();

  AccX = rawAccX / 16384.0;
  AccZ = rawAccZ / 16384.0;
  GyroY = rawGyroY / 131.0 - GyroErrorY;

  previousTime = currentTime;
  currentTime = millis();
  elapsedTime = (currentTime - previousTime) / 1000.0;

  float angleY = atan2(-AccX, AccZ) * 180.0 / PI;
  float frontY = angleY - angleYZero;
  compAngleY = 0.96 * (compAngleY + GyroY * elapsedTime) + 0.04 * frontY;
}

void calculate_IMU_error() {
  Serial.println("Calibrating MPU6050... keep it still.");

  const int samples = 300;
  float gyroSumY = 0;
  float angleSumY = 0;

  for (int i = 0; i < samples; i++) {
    Wire.beginTransmission(MPU);
    Wire.write(0x3B);
    Wire.endTransmission(false);
    Wire.requestFrom(MPU, 14, true);

    int16_t rawAccX = Wire.read() << 8 | Wire.read();
    Wire.read();
    Wire.read();
    int16_t rawAccZ = Wire.read() << 8 | Wire.read();

    Wire.read();
    Wire.read();

    Wire.read();
    Wire.read();
    int16_t rawGyroY = Wire.read() << 8 | Wire.read();
    Wire.read();
    Wire.read();

    AccX = rawAccX / 16384.0;
    AccZ = rawAccZ / 16384.0;
    GyroY = rawGyroY / 131.0;

    gyroSumY += GyroY;
    angleSumY += atan2(-AccX, AccZ) * 180.0 / PI;

    delay(5);
  }

  GyroErrorY = gyroSumY / samples;
  angleYZero = angleSumY / samples;
  compAngleY = 0;

  Serial.println("IMU Calibration Complete");
  currentTime = millis();
  previousTime = currentTime;
}

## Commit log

2026-05-21 workshop commit
    [1 - base.stl, 2 - button_element.stl, 3 - jack element 1 (thick).stl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]
2026-05-21 Add project documentation and PCB BOM
    [BOM.csv]
